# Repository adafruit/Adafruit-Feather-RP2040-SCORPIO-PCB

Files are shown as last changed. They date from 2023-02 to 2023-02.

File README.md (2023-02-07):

## Adafruit Feather RP2040 SCORPIO 8 Channel NeoPixel Driver PCB

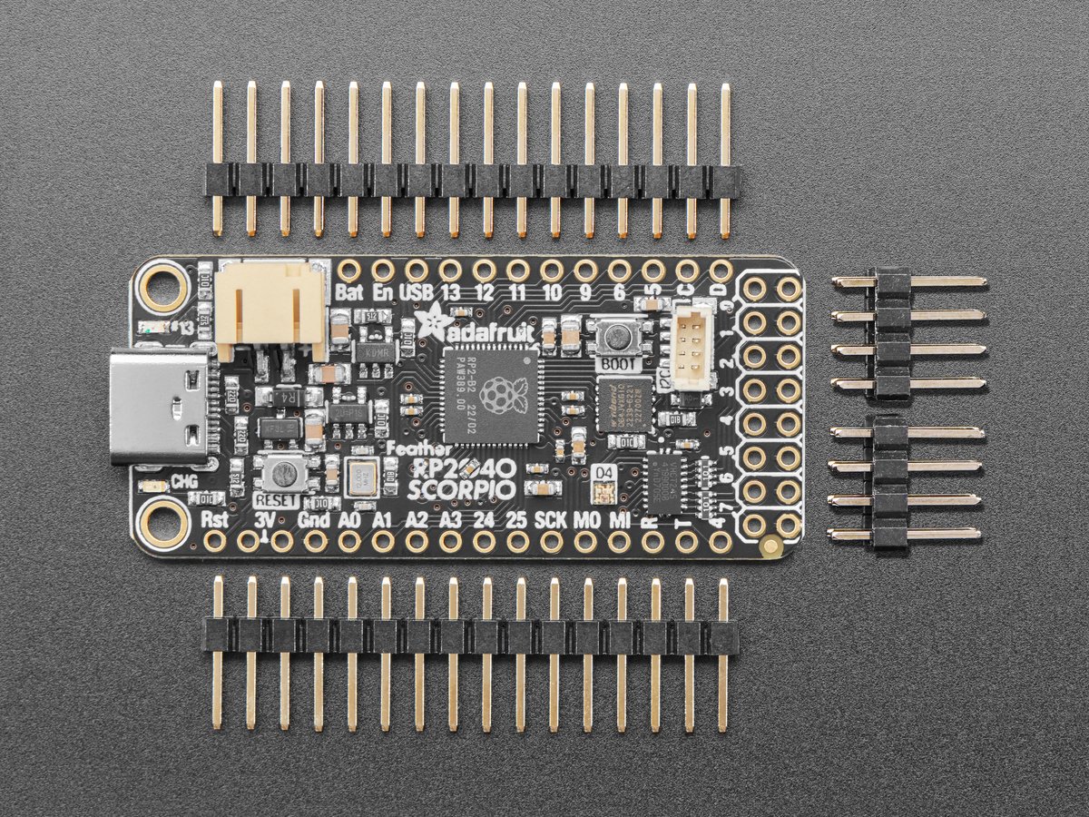
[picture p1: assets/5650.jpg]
<a href="http://www.adafruit.com/products/5650"><br/>
Click here to purchase one from the Adafruit shop</a>

PCB files for the Adafruit Feather RP2040 SCORPIO 8 Channel NeoPixel Driver. 

Format is EagleCAD schematic and board layout
* https://www.adafruit.com/product/5650

### Description

If there is one thing Adafruit is known for, its mega-blinky-fun-rainbow-LEDs. We just love sticking NeoPixels anywhere and everywhere. When we saw the new 'PIO' peripheral on the RP2040 from Raspberry Pi, we just knew it would be perfect for driving large quantities of NeoPixels. So we created this board, the Adafruit Feather RP2040 SCORPIO, designed specifically for NeoPixel (WS2812) driving but also good for various other PIO-based projects that want to take advantage of the Feather pinout with 8 separate consecutive outputs (or inputs).

The RP2040 PIO state machine is perfect for LED driving: it can generate perfect waveforms, with up to 8 outputs concurrently, all through DMA. That means that you don't need to use any processor time to bit-bang-out the LED data. Just set up the buffer and tell the PIO peripheral to 'make it so' and it will shove that data to the 8 outputs without delay while your code can continue to read buttons, play music, run CircuitPython - whatever you like!

The SCORPIO has a clever pinout, where all the standard Feather pins are the same as the GPIO pins, plus the standard I2C, SPI and UART lines - and theres still enough pins left over to have 8 consecutive pins for PIO usage on GPIO16 through GPIO23 inclusive.

To make NeoPixel usage glitch-free there is a 3V->5V level shifter so that the output logic is 5V. If you happen to want 3V signals, you can adjust the shifter voltage with a jumper on the bottom. It's also possible to flip the direction of the level shifter to make the 8 I/O pins inputs - say for making a logic analyzer - with a directional jumper selection also on the bottom of the PCB.

The RP2040 SCORPIO also has a ton of RAM, 264KB, making it trivial to buffer huge numbers of NeoPixels…several thousand if needed. In fact there's so much RAM you can even dither the pixels to for finer brightness control, for better-looking LEDs at low brightness or for gamma correction.

### License

Adafruit invests time and resources providing this open source design, please support Adafruit and open-source hardware by purchasing products from [Adafruit](https://www.adafruit.com)!

Designed by Limor Fried/Ladyada for Adafruit Industries.

Creative Commons Attribution/Share-Alike, all text above must be included in any redistribution. 
See license.txt for additional details.

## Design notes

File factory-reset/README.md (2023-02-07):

## Factory Reset file - Feather RP2040 SCORPIO 8 Channel NeoPixel Driver

This is the factory reset file for the Feather RP2040 SCORPIO 8 Channel NeoPixel Driver.

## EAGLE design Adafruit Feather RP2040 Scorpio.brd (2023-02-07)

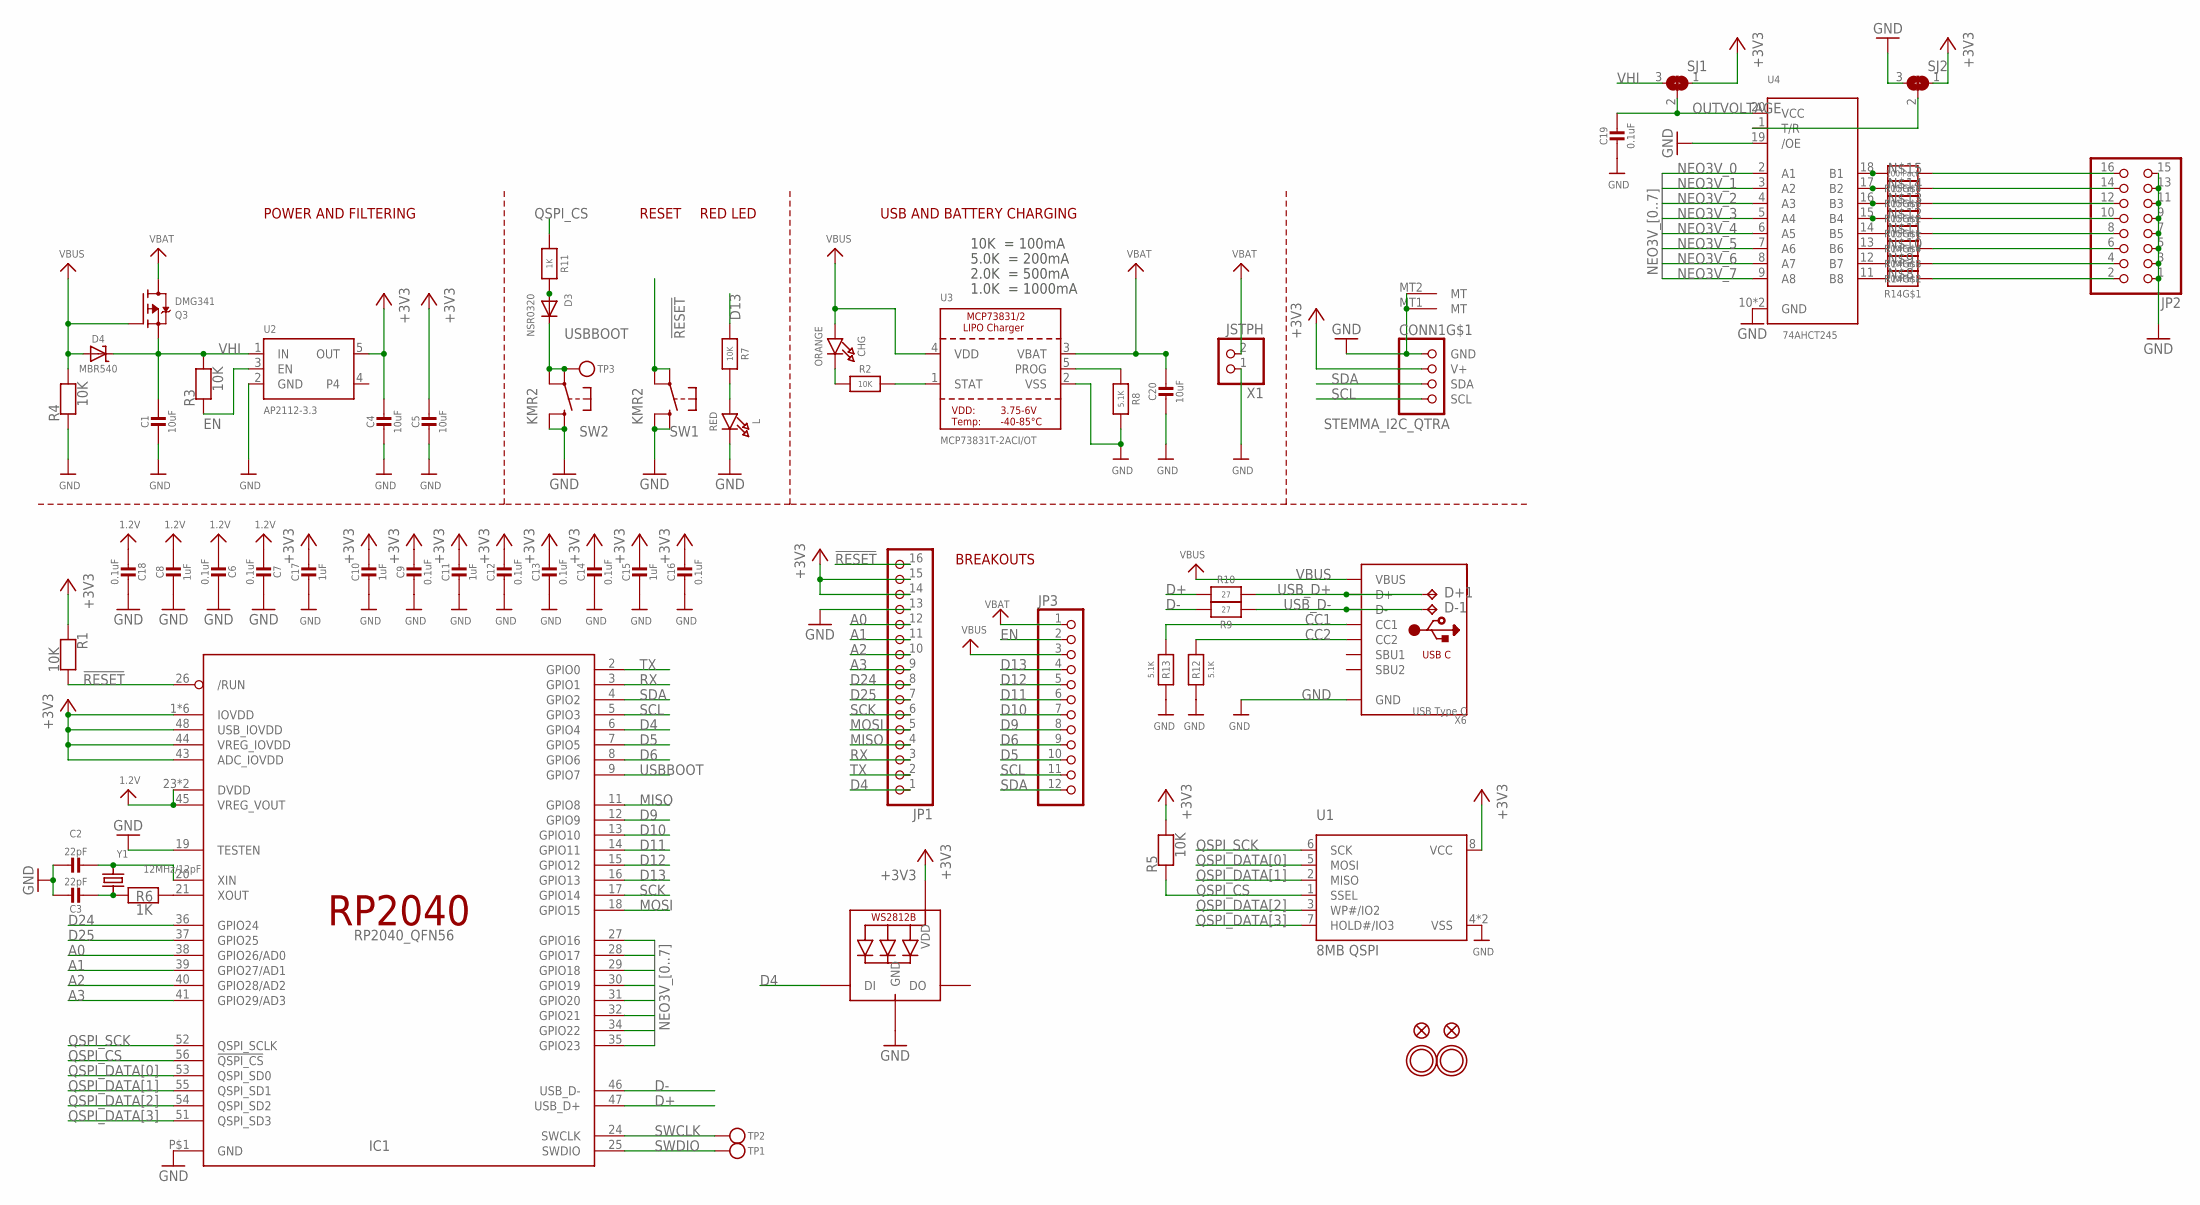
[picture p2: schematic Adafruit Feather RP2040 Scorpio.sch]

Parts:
C1, C4, C5, C20: 10uF; 0805-NO
C2, C3: 22pF; _0402NO
C6, C7, C9, C12, C13, C14, C16, C18, C19: 0.1uF; _0402NO
C8, C10, C11, C15, C17: 1uF; 0603-NO
CHG: ORANGE; CHIPLED_0603_NOOUTLINE
CONN1: STEMMA_I2C_QTRA; JST_SH4_RA
D3: NSR0320; SOD-323F
D4: MBR540; SOD-123
D+1: TPB1,27; B1,27
D-1: TPB1,27; B1,27
IC1: RP2040_QFN56; QFN56_7MM_REDUCEDEPAD
JP1: HEADER-1X16ROUND; 1X16_ROUND
JP2: HEADER-2X8; 2X08
JP3: HEADER-1X12; 1X12_ROUND
L: RED; CHIPLED_0603_NOOUTLINE
LED1: WS2812B_SK6805_1515; SK6805_1515
Q3: DMG341; SOT23-R
R1, R2, R3, R4, R5, R7: 10K; 0603-NO
R6, R11: 1K; 0603-NO
R8, R12, R13: 5.1K; 0603-NO
R9, R10: 27; 0603-NO
R14, R15: 100 Pack; RESPACK_4X0402
SJ1, SJ2: SOLDERJUMPER_2WAY; SOLDERJUMPER_2WAY_OPEN_NOPASTE
SW1, SW2: KMR2; BTN_KMR2_4.6X2.8
TP1, TP2, TP3: TESTPOINTROUND1.5MMNO; TESTPOINT_ROUND_1.5MM_NO
U1: 8MB QSPI; USON8_4X4
U2: AP2112-3.3; SOT23-5; JLC_ROTATION 0
U3: MCP73831T-2ACI/OT; SOT23-5
U4: 74AHCT245; 20-DHVQFN
U$31, U$32: MOUNTINGHOLE2.5; MOUNTINGHOLE_2.5_PLATED
U$34, U$35: FIDUCIAL_1MM
X1: JSTPH; JSTPH2_BATT
X6: USB Type C; USB_C_CUSB31-CFM2AX-01-X
Y1: 12MHz/12pF; CRYSTAL_2.5X2

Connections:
1.2V: C6.2, C7.2, C8.1, C18.2, IC1.23 (DVDD), IC1.45 (VREG_VOUT), IC1.50 (DVDD)
!RESET: IC1.26 (/RUN), JP1.16, R1.2, SW1.A, SW1.A' (P1)
+3V3: C4.1, C5.1, C9.1, C10.1, C11.1, C12.1, C13.1, C14.1, C15.1, C16.1, C17.1, CONN1.2 (V+), IC1.1 (IOVDD), IC1.10 (IOVDD), IC1.22 (IOVDD), IC1.33 (IOVDD), IC1.42 (IOVDD), IC1.43 (ADC_IOVDD), IC1.44 (VREG_IOVDD), IC1.48 (USB_IOVDD), IC1.49 (IOVDD), JP1.14, JP1.15, LED1.2 (VDD), R1.1, R5.2, SJ1.1, SJ2.1, U1.8 (VCC), U2.5 (OUT)
A0: IC1.38 (GPIO26/AD0), JP1.12
A1: IC1.39 (GPIO27/AD1), JP1.11
A2: IC1.40 (GPIO28/AD2), JP1.10
A3: IC1.41 (GPIO29/AD3), JP1.9
CC1: R13.2, X6.A5 (CC1)
CC2: R12.2, X6.B5 (CC2)
D4: IC1.6 (GPIO4), JP1.1, LED1.1 (DI)
D5: IC1.7 (GPIO5), JP3.10
D6: IC1.8 (GPIO6), JP3.9
D9: IC1.12 (GPIO9), JP3.8
D10: IC1.13 (GPIO10), JP3.7
D11: IC1.14 (GPIO11), JP3.6
D12: IC1.15 (GPIO12), JP3.5
D13: IC1.16 (GPIO13), JP3.4, R7.1
D24: IC1.36 (GPIO24), JP1.8
D25: IC1.37 (GPIO25), JP1.7
D+: IC1.47 (USB_D+), R10.2
D-: IC1.46 (USB_D-), R9.2
EN: JP3.2, R3.1, U2.3 (EN)
GND: C1.2, C2.1, C3.1, C4.2, C5.2, C6.1, C7.1, C8.2, C9.2, C10.2, C11.2, C12.2, C13.2, C14.2, C15.2, C16.2, C17.2, C18.1, C19.2, C20.2, CONN1.1 (GND), CONN1.MT1 (MT), CONN1.MT2 (MT), IC1.19 (TESTEN), IC1.P$1 (GND), JP1.13, JP2.1, JP2.3, JP2.5, JP2.7, JP2.9, JP2.11, JP2.13, JP2.15, L.C, LED1.4 (GND), R4.1, R8.2, R12.1, R13.1, SJ2.3, SW1.B (S), SW1.B' (S1), SW2.B (S), SW2.B' (S1), U1.4 (VSS), U1.PAD (VSS), U2.2 (GND), U3.2 (VSS), U4.10 (GND), U4.19 (/OE), U4.21 (GND), X1.1, X6.A1B12 (GND), X6.B1A12 (GND)
MISO: IC1.11 (GPIO8), JP1.4
MOSI: IC1.18 (GPIO15), JP1.5
unnamed: CHG.C, R2.1
unnamed: L.A, R7.2
unnamed: R2.2, U3.1 (STAT)
unnamed: R8.1, U3.5 (PROG)
unnamed: C2.2, IC1.20 (XIN), Y1.3 (2)
unnamed: C3.2, R6.1, Y1.1
unnamed: IC1.21 (XOUT), R6.2
unnamed: R14.8 (2), U4.11 (B8)
unnamed: R14.7 (2), U4.12 (B7)
unnamed: R14.6 (2), U4.13 (B6)
unnamed: R14.5 (2), U4.14 (B5)
unnamed: R15.8 (2), U4.15 (B4)
unnamed: R15.7 (2), U4.16 (B3)
unnamed: R15.6 (2), U4.17 (B2)
unnamed: R15.5 (2), U4.18 (B1)
unnamed: D3.A, R11.2
unnamed: SJ2.2, U4.1 (T/R)
NEO0: JP2.16, R15.4 (1)
NEO1: JP2.14, R15.3 (1)
NEO2: JP2.12, R15.2 (1)
NEO3: JP2.10, R15.1
NEO3V_0: IC1.27 (GPIO16), U4.2 (A1)
NEO3V_1: IC1.28 (GPIO17), U4.3 (A2)
NEO3V_2: IC1.29 (GPIO18), U4.4 (A3)
NEO3V_3: IC1.30 (GPIO19), U4.5 (A4)
NEO3V_4: IC1.31 (GPIO20), U4.6 (A5)
NEO3V_5: IC1.32 (GPIO21), U4.7 (A6)
NEO3V_6: IC1.34 (GPIO22), U4.8 (A7)
NEO3V_7: IC1.35 (GPIO23), U4.9 (A8)
NEO4: JP2.8, R14.4 (1)
NEO5: JP2.6, R14.3 (1)
NEO6: JP2.4, R14.2 (1)
NEO7: JP2.2, R14.1
OUTVOLTAGE: C19.1, SJ1.2, U4.20 (VCC)
QSPI_CS: IC1.56 (!QSPI_CS), R5.1, R11.1, U1.1 (SSEL)
QSPI_DATA[0]: IC1.53 (QSPI_SD0), U1.5 (MOSI)
QSPI_DATA[1]: IC1.55 (QSPI_SD1), U1.2 (MISO)
QSPI_DATA[2]: IC1.54 (QSPI_SD2), U1.3 (WP#/IO2)
QSPI_DATA[3]: IC1.51 (QSPI_SD3), U1.7 (HOLD#/IO3)
QSPI_SCK: IC1.52 (QSPI_SCLK), U1.6 (SCK)
RX: IC1.3 (GPIO1), JP1.3
SCK: IC1.17 (GPIO14), JP1.6
SCL: CONN1.4 (SCL), IC1.5 (GPIO3), JP3.11
SDA: CONN1.3 (SDA), IC1.4 (GPIO2), JP3.12
SWCLK: IC1.24 (SWCLK), TP2.P$1
SWDIO: IC1.25 (SWDIO), TP1.P$1
TX: IC1.2 (GPIO0), JP1.2
USBBOOT: D3.C, IC1.9 (GPIO7), SW2.A, SW2.A' (P1), TP3.P$1
USB_D+: D+1.TP, R10.1, X6.A6 (D+), X6.B6 (D+)
USB_D-: D-1.TP, R9.1, X6.A7 (D-), X6.B7 (D-)
VBAT: C20.1, JP3.1, Q3.3 (D), U3.3 (VBAT), X1.2
VBUS: CHG.A, D4.A, JP3.3, Q3.1 (G), R4.2, U3.4 (VDD), X6.A4B9 (VBUS), X6.B4A9 (VBUS)
VHI: C1.1, D4.C, Q3.2 (S), R3.2, SJ1.3, U2.1 (IN)

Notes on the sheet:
POWER AND FILTERING
RESET
10K = 100mA
5.0K = 200mA
2.0K = 500mA
1.0K = 1000mA
USB AND BATTERY CHARGING
BREAKOUTS
RED LED

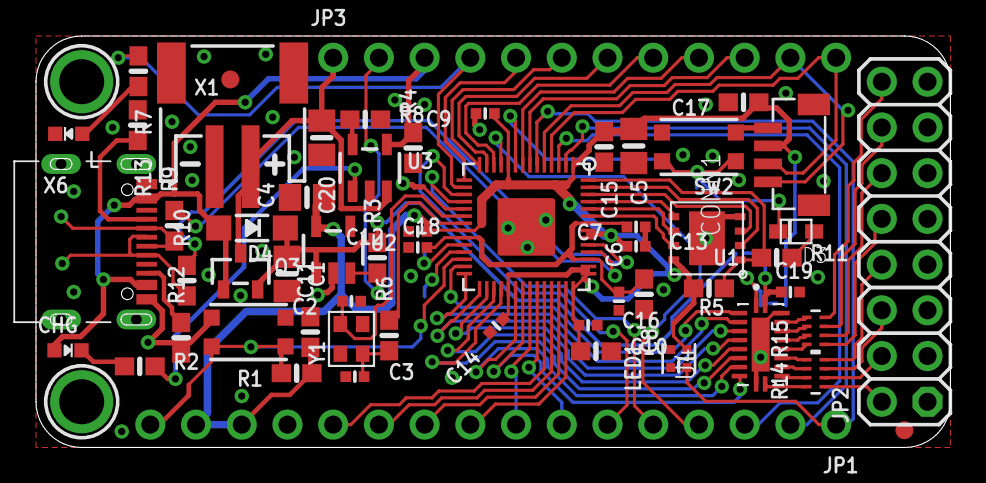
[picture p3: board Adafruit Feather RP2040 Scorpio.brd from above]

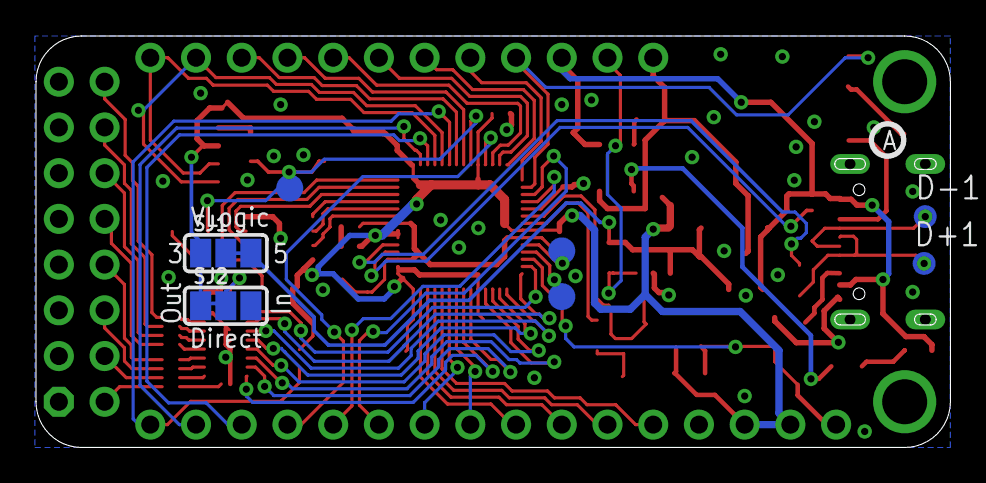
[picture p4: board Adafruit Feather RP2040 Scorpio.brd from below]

Board: 2 copper layers, 50.8 x 22.9 mm, 69 parts (9 on the bottom side), 78 nets.

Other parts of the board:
U$12: SCORPIO_TOP
U$13: PCBFEAT-REV-040
U$28: SCORPIO_BOT

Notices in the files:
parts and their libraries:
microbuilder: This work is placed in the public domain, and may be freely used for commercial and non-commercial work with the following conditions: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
